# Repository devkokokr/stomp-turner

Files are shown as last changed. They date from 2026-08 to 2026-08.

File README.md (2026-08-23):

English | [한국어](README.ko.md)

# Wireless Music Page Turner Pedal

A BLE foot pedal for turning pages in sheet music apps. Step on it and the page turns, no cables to your tablet or phone.

Built around a Waveshare ESP32-S3-Zero devkit on a custom carrier board. The pedal shows up as a standard BLE HID keyboard, so it works with forScore, piaScore, and any other app that responds to keyboard shortcuts.

## Status

Hardware design is finalized and the first PCB/PCBA run is in progress. Firmware covers footswitch input (debouncing plus key-mapping profiles), BLE HID over NimBLE, battery monitoring with low-voltage cutoff, the connect switch, and the status LED, but none of it has been validated against real hardware yet.

## How it works

- Two latching footswitches wired to GPIO4 (left / "previous") and GPIO5 (right / "next"). Since the switches are latching rather than momentary, the firmware tracks GPIO edges rather than levels so each step registers as a single press.
- A 4-bit DIP switch selects a key-mapping profile at boot, so the same pedal can send arrow keys, Page Up/Down, or presentation-style Backspace/Space depending on which app it's paired with.
- A dedicated switch triggers BLE pairing mode. The devkit's onboard BOOT/RESET buttons still handle flashing and reset.
- Runs off a single 18650 cell charged through a TP4056 module, with battery voltage sensed via ADC for low-voltage cutoff.

### GPIO map

| GPIO | Function |
|---|---|
| GP4  | Left footswitch ("previous") |
| GP5  | Right footswitch ("next") |
| GP6–GP9 | DIP switch (4-bit key-mapping profile select) |
| GP10 | BLE pairing switch |
| GP11 | Battery voltage sense (ADC) |
| GP12 | Status LED |
| GP13 | Debug header only |

GPIO21 and GPIO33–37 are reserved by the devkit itself (onboard RGB LED and PSRAM) and are not used on the carrier board.

### Key-mapping profiles

| # | DIP (GP9 GP8 GP7 GP6) | Previous | Next | Target |
|---|---|---|---|---|
| 0 | `0000` (default) | Left Arrow | Right Arrow | Most sheet music apps (forScore, etc.) |
| 1 | `0001` | Up Arrow | Down Arrow | Vertical-scroll viewers |
| 2 | `0010` | Page Up | Page Down | Desktop PDF readers |
| 3 | `0011` | Backspace | Space | Presentation "clicker" style (PowerPoint/Keynote) |
| 4 | `0100` | Backspace | Enter | Viewers that page forward on Enter |

Unused combinations fall back to profile 0.

## Firmware

Built with ESP-IDF (not Arduino/PlatformIO), targeting `esp32s3`. BLE HID uses the `esp_hid` component over the NimBLE backend, BLE-only (no Bluetooth Classic).

```
idf.py set-target esp32s3   # already the default via sdkconfig.defaults
idf.py build
idf.py -p <PORT> flash monitor
```

## Hardware source

Schematic, Gerber files, and 3D model are in [`hardware/`](hardware/).

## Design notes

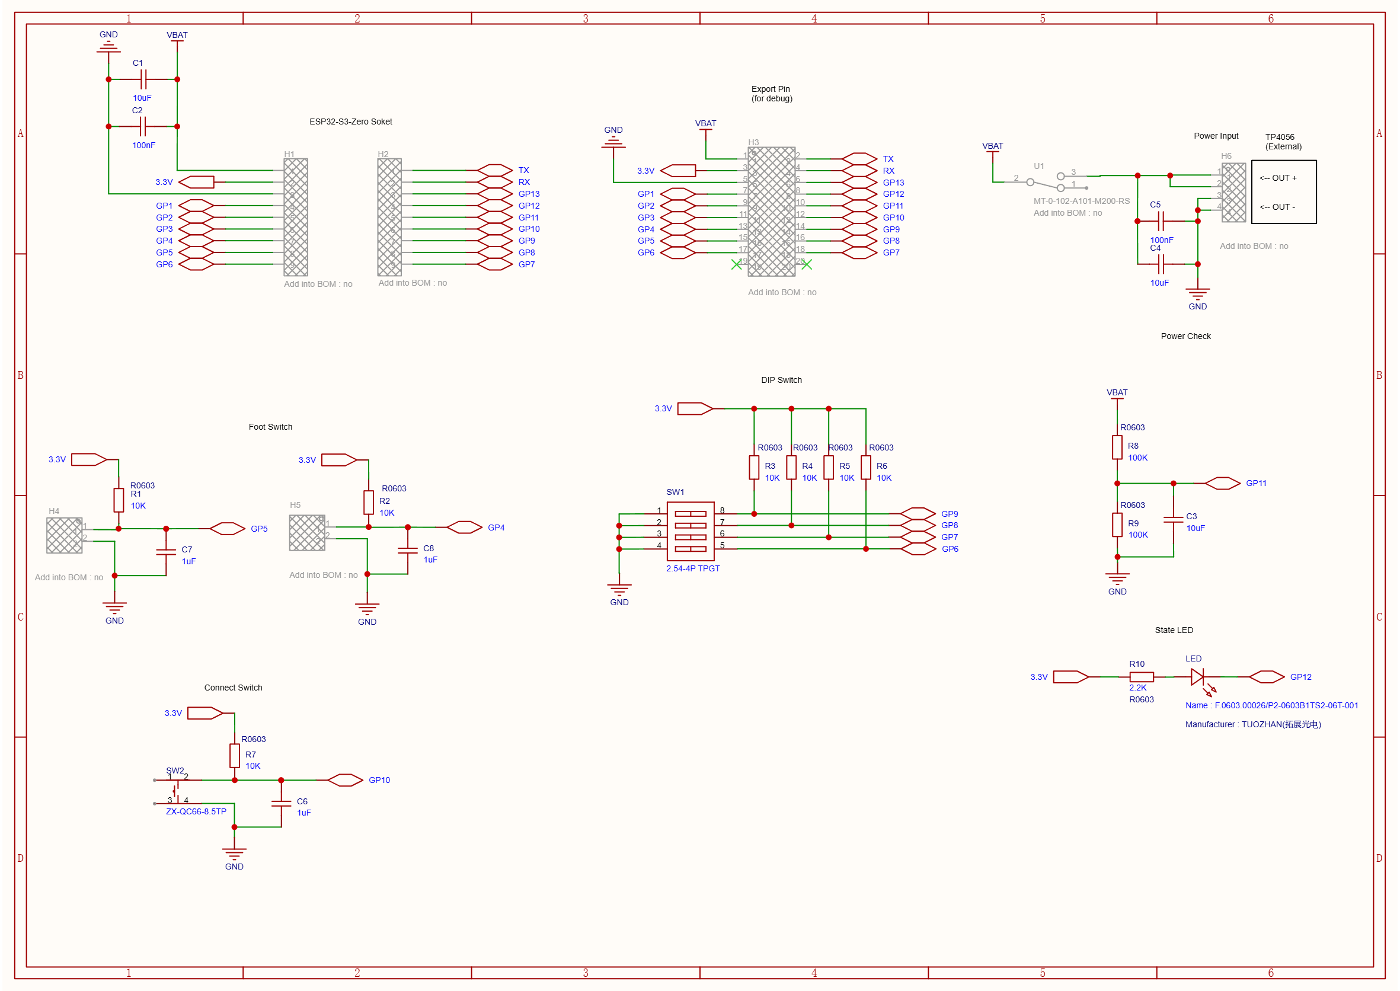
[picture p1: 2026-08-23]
hardware/schematic/schematic.png

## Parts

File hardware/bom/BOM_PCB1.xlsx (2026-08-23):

 |  |  | BOM
Item # | *Designator | *Qty | Manufacturer | *Mfg Part # | Description / Value | *Package/Footprint | Type | Your Instructions / Notes
1 | C1,C3,C4 | 3 | SAMSUNG(三星) | CL10A106MA8NRNC | 10uF | C0603 | SMD
2 | C2,C5 | 2 | SAMSUNG(三星) | CL10B104KB8NNNC | 100nF | C0603 | SMD
3 | C6,C7,C8 | 3 | SAMSUNG(三星) | CL10A105KO8NNNC | 1uF | C0603 | SMD
4 | LED | 1 | TUOZHAN(拓展光电) | F.0603.00026/P2-0603B1TS2-06T-001 | LED0603-RD | LED0603-RD | SMD
5 | R1,R2,R3,R4,R5,R6,R7 | 7 | YAGEO(国巨) | RT0603BRD0710KL | 10kΩ | R0603 | SMD
6 | R8,R9 | 2 | YAGEO(国巨) | RT0603BRE07100KL | 100kΩ | R0603 | SMD
7 | R10 | 1 | YAGEO(国巨) | AC0603FR-072K2L | 2.2kΩ | R0603 | SMD
8 | SW1 | 1 | SHOU HAN(首韩) | 2.54-4P TPGT | SW-SMD_8P-L10.2-W6.2-P2.54-LS9.4 | SW-SMD_8P-L10.2-W6.2-P2.54-LS9.4 | SMD
9 | SW2 | 1 | Megastar(兆星) | ZX-QC66-8.5TP | KEY-SMD_4P-L6.0-W6.0-P4.50-LS8.6_H8.5 | KEY-SMD_4P-L6.0-W6.0-P4.50-LS8.6_H8.5 | SMD
Need a quick and accurante quote? Need an efficient production? Please read SMT Ordering Necessary Files & Info in 1 minute. Thank you very much! (https://www.pcbway.com/smt_ordering_guide.html)
Click for Instructions on How to Create a BOM (https://www.pcbway.com/blog/PCB_Assembly/How_to_Build_a_BOM__Bill_Of_Materials_.html)

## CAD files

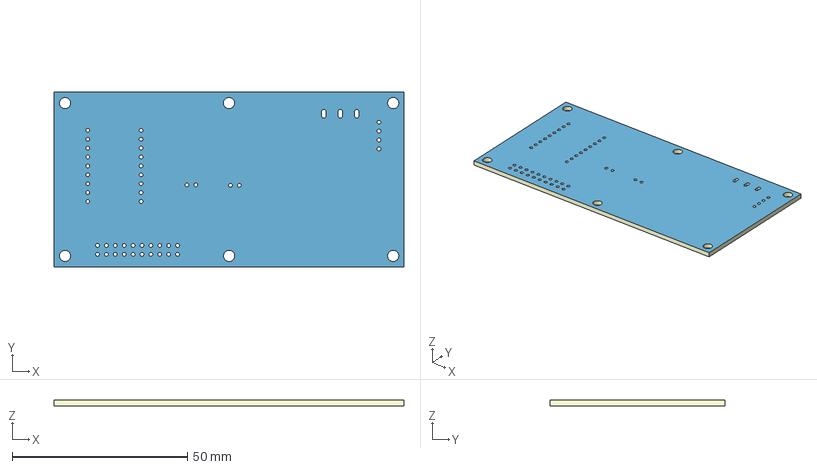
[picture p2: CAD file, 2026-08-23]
hardware/3d/3D_PCB1.step
100.0 x 50.0 x 1.60 mm
Board~3fdd
TopCopper~3fdd
BottomCopper~3fdd
TopSilkscreen~3fdd
BottomSilkscreen~3fdd
TopFpcStiffener~3fdd
BottomFpcStiffener~3fdd

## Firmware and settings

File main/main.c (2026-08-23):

#include "esp_log.h"

#include "freertos/FreeRTOS.h"
#include "freertos/task.h"

#include "battery.h"
#include "ble_hid.h"
#include "connect_switch.h"
#include "input.h"
#include "led.h"
#include "power.h"

static const char *TAG = "stomp-turner";

void app_main(void)
{
    power_init();
    ble_hid_init();

    // Every task running in the system is created here so the full task
    // list is visible in one place.
    input_init();
    xTaskCreate(input_task, INPUT_TASK_NAME, INPUT_TASK_STACK_SIZE, NULL, INPUT_TASK_PRIORITY, NULL);

    battery_init();
    xTaskCreate(battery_task, BATTERY_TASK_NAME, BATTERY_TASK_STACK_SIZE, NULL, BATTERY_TASK_PRIORITY, NULL);

    connect_switch_init();
    xTaskCreate(connect_switch_task, CONNECT_SWITCH_TASK_NAME, CONNECT_SWITCH_TASK_STACK_SIZE, NULL,
                CONNECT_SWITCH_TASK_PRIORITY, NULL);

    led_init();
    xTaskCreate(led_task, LED_TASK_NAME, LED_TASK_STACK_SIZE, NULL, LED_TASK_PRIORITY, NULL);

    ESP_LOGI(TAG, "stomp-turner boot OK");
}

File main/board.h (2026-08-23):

#pragma once

#include "driver/gpio.h"

// Foot switches (latching/toggle type, not momentary — see firmware notes)
#define BOARD_GPIO_FOOTSWITCH_LEFT   GPIO_NUM_4  // "previous"
#define BOARD_GPIO_FOOTSWITCH_RIGHT  GPIO_NUM_5  // "next"

// DIP switch, 4 bits, forms the key-mapping profile index (GP9 = MSB, GP6 = LSB)
#define BOARD_GPIO_DIP_BIT0          GPIO_NUM_6
#define BOARD_GPIO_DIP_BIT1          GPIO_NUM_7
#define BOARD_GPIO_DIP_BIT2          GPIO_NUM_8
#define BOARD_GPIO_DIP_BIT3          GPIO_NUM_9

#define BOARD_GPIO_CONNECT_BUTTON    GPIO_NUM_10
#define BOARD_GPIO_BATTERY_ADC       GPIO_NUM_11
#define BOARD_GPIO_STATUS_LED        GPIO_NUM_12
